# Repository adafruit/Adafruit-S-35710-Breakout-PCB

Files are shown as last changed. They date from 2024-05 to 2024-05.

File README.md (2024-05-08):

## Adafruit S-35710 Low-Power Wake Up Timer Breakout - STEMMA QT / Qwiic PCB

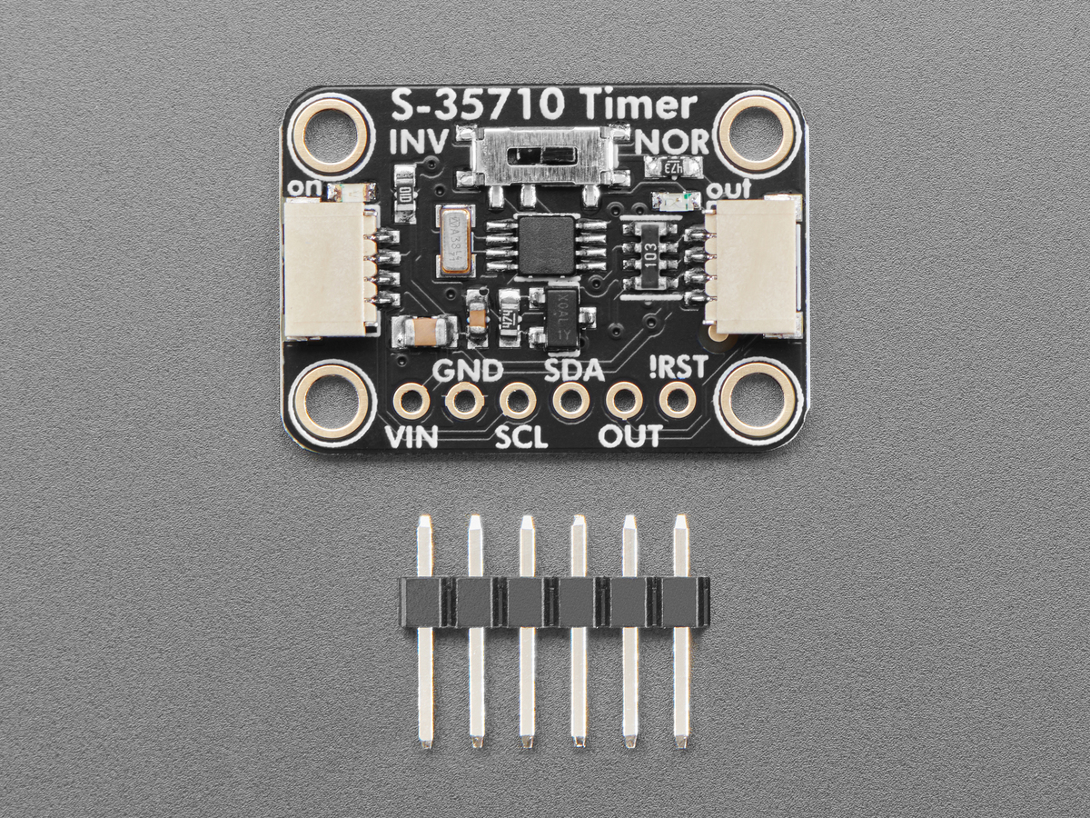
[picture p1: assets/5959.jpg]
<a href="http://www.adafruit.com/products/5959"><br/>
Click here to purchase one from the Adafruit shop</a>

PCB files for the Adafruit S-35710 Low-Power Wake Up Timer Breakout - STEMMA QT / Qwiic. 

Format is EagleCAD schematic and board layout
* https://www.adafruit.com/product/5959

### Description

The Adafruit S-35710 Wake Up Timer is a low power 'watchdog timer' chip that can be programmed to alert with a digitally-configurable alarm from 1 second up to 194 days, thanks to a 24-bit second counter. It's an interesting alternative to a real time clock or internal sleep timer and might be useful for some ultra-low-power projects that want to have a separate (and possibly separately-powered) chip to handle time-keeping and alarms. We covered this component on EYE ON NPI and thought it would make for a nice breakout in the shop.

Usage is pretty simple: on I2C write of the timer register, the chip starts counting from 0 seconds up and the OUT pin goes high. When the count matches the timer register, the OUT pin goes low. Simple, and like we mentioned, it's very low power, drawing only 0.2uA. The output is open-drain, and if you want to have it be inverted, there's a switch that will put the signal through an N-channel FET so the polarity goes the other way.

One thing to note, is that on power-up the OUT line is default low, which means its not good for a low-power sleep manager, only for watch-dog-like timings. That is to say, you cannot connect this to your microcontroller's reset or enable line to self-depower because it will be disabled/reset when powered up. Still, maybe a useful chip for some folks who want to signal after a long delay or have a more complex power management scheme.

To get you going fast, we spun up a custom-made PCB in the STEMMA QT form factor, making it easy to interface with. The STEMMA QT connectors on either side are compatible with the SparkFun Qwiic I2C connectors. This allows you to make solderless connections between your development board and the S-35710 or to chain it with a wide range of other sensors and accessories using a compatible cable.

### License

Adafruit invests time and resources providing this open source design, please support Adafruit and open-source hardware by purchasing products from [Adafruit](https://www.adafruit.com)!

Designed by Limor Fried/Ladyada for Adafruit Industries.

Creative Commons Attribution/Share-Alike, all text above must be included in any redistribution. 
See license.txt for additional details.

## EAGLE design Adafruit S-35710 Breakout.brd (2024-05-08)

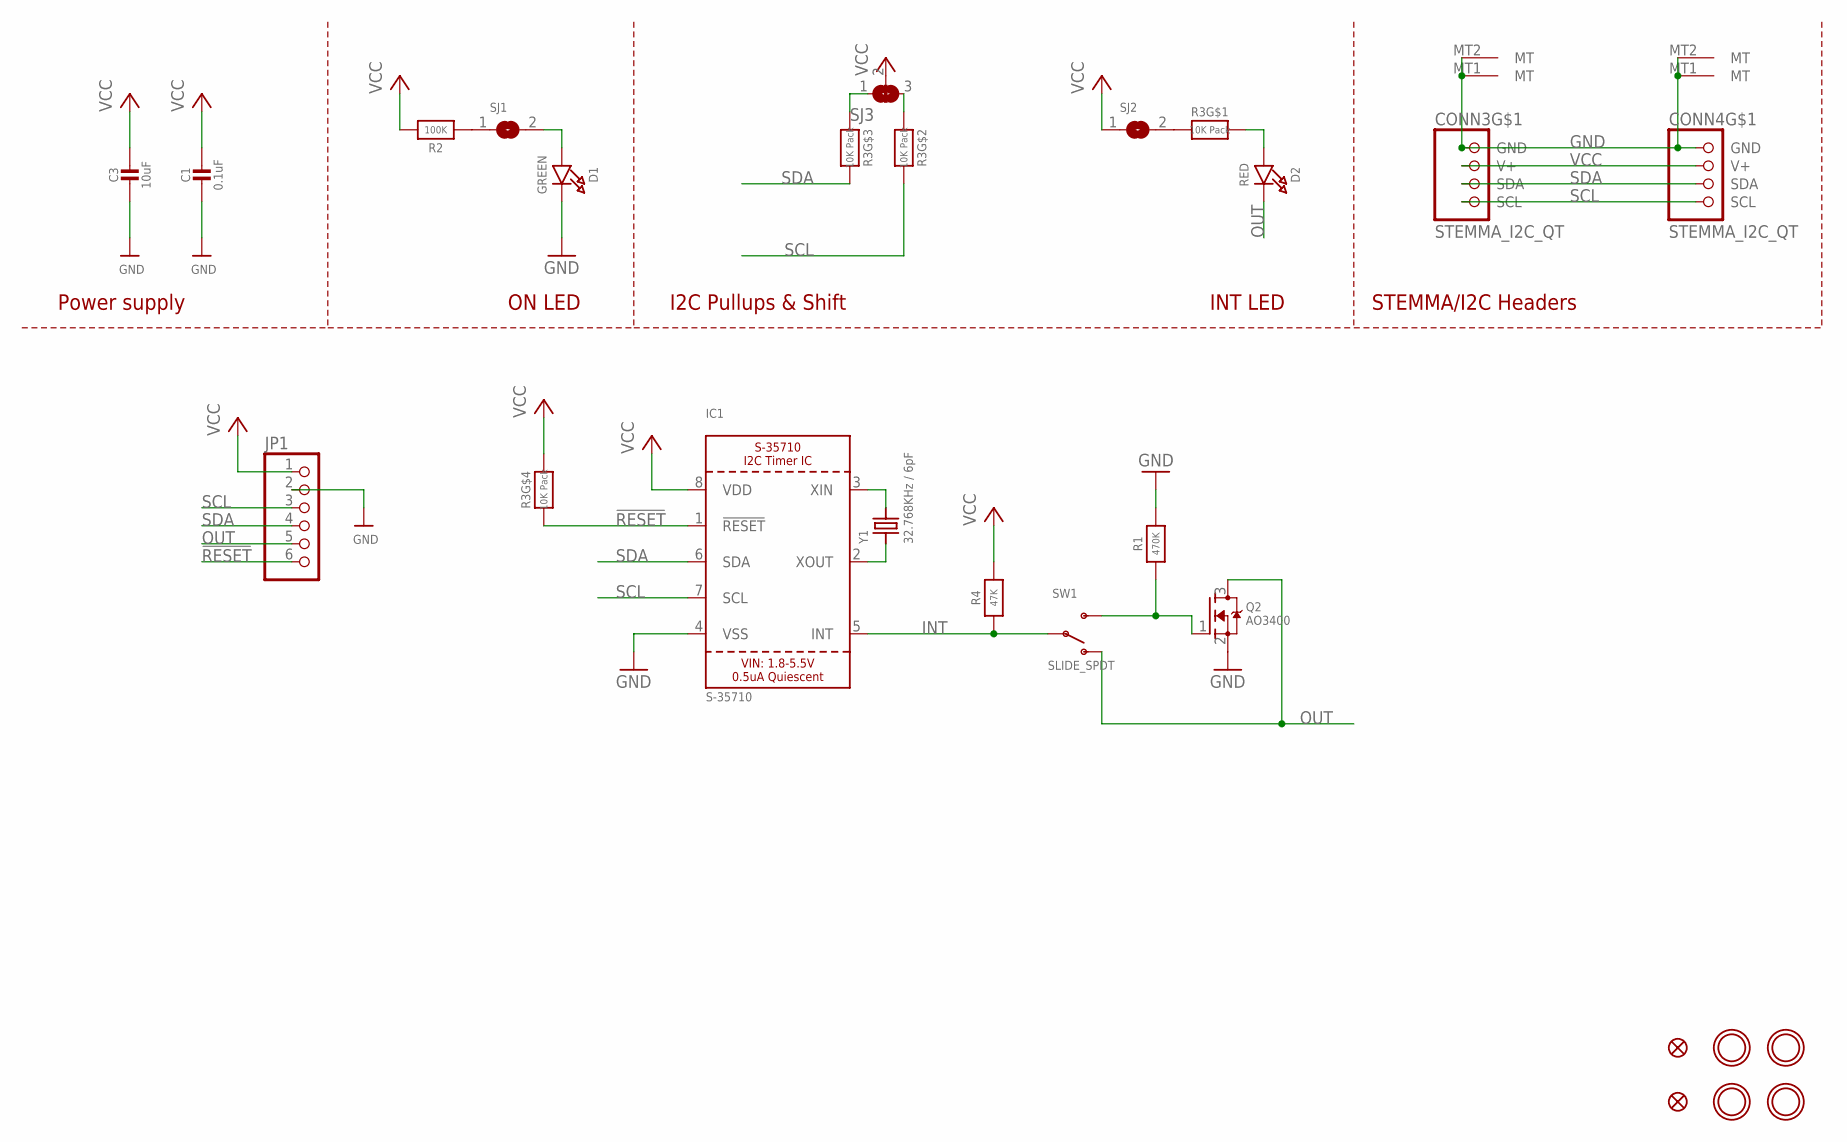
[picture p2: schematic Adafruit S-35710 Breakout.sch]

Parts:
C1: 0.1uF; 0603-NO
C3: 10uF; 0805-NO
CONN3, CONN4: STEMMA_I2C_QT; JST_SH4
D1: GREEN; CHIPLED_0603_NOOUTLINE
D2: RED; CHIPLED_0603_NOOUTLINE
FID3, FID4: FIDUCIAL_1MM
IC1: S-35710; MSOP8_0.65MM
JP1: HEADER-1X670MIL; 1X06_ROUND_70
Q2: AO3400; SOT23-WIDE
R1: 470K; 0603-NO
R2: 100K; 0603-NO
R3: 10K Pack; RESPACK_4X0603
R4: 47K; 0603-NO
SJ1, SJ2: SOLDERJUMPERCLOSED; SOLDERJUMPER_CLOSEDWIRE
SJ3: SOLDERJUMPER_2WAY; SOLDERJUMPER_2WAY_OPEN_NOPASTE
SW1: SLIDE_SPDT; SPDT_SMT_SSSS811101
U$1, U$17, U$19, U$21: MOUNTINGHOLE2.5; MOUNTINGHOLE_2.5_PLATED
Y1: 32.768KHz / 6pF; XTAL3215

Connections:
!RESET: IC1.1 (!RESET), JP1.6, R3.4 (1)
GND: C1.2, C3.2, CONN3.1 (GND), CONN3.MT1 (MT), CONN3.MT2 (MT), CONN4.1 (GND), CONN4.MT1 (MT), CONN4.MT2 (MT), D1.C, IC1.4 (VSS), JP1.2, Q2.2 (S), R1.2
INT: IC1.5 (INT), R4.1, SW1.B
unnamed: D1.A, SJ1.2
unnamed: R3.1, SJ2.2
unnamed: R2.1, SJ1.1
unnamed: D2.A, R3.8 (2)
unnamed: IC1.3 (XIN), Y1.P$2 (2)
unnamed: IC1.2 (XOUT), Y1.P$1 (1)
unnamed: R3.3 (1), SJ3.1
unnamed: Q2.1 (G), R1.1, SW1.C (S)
unnamed: R3.2 (1), SJ3.3
OUT: D2.C, JP1.5, Q2.3 (D), SW1.A (O)
SCL: CONN3.4 (SCL), CONN4.4 (SCL), IC1.7 (SCL), JP1.3, R3.7 (2)
SDA: CONN3.3 (SDA), CONN4.3 (SDA), IC1.6 (SDA), JP1.4, R3.6 (2)
VCC: C1.1, C3.1, CONN3.2 (V+), CONN4.2 (V+), IC1.8 (VDD), JP1.1, R2.2, R3.5 (2), R4.2, SJ2.1, SJ3.2

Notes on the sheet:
I2C Pullups & Shift
STEMMA/I2C Headers
ON LED
Power supply
INT LED

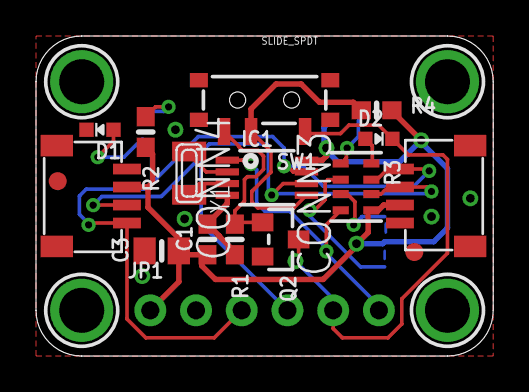
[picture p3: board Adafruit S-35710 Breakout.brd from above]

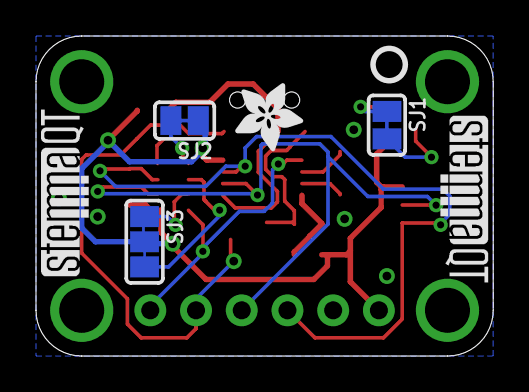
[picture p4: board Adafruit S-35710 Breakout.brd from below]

Board: 2 copper layers, 25.4 x 17.8 mm, 47 parts (15 on the bottom side), 16 nets.

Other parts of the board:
PLABEL0: PLABEL0
PLABEL1: PLABEL1
PLABEL2: PLABEL2
PLABEL3: PLABEL3
PLABEL4: PLABEL4
PLABEL5: PLABEL5
PLABEL6: PLABEL6
PLABEL7: PLABEL7
PLABEL8: PLABEL8
PLABEL9: PLABEL9
PLABEL10: PLABEL10
PLABEL11: PLABEL11
PLABEL13: PLABEL13
PLABEL14: PLABEL14
PLABEL15: PLABEL15
PLABEL16: PLABEL16
PLABEL17: PLABEL17
PLABEL18: PLABEL18
PLABEL19: PLABEL19
U$22: ADAFRUIT_3.5MM
U$25: PCBFEAT-REV-040
U$30, U$31: STEMMAQT

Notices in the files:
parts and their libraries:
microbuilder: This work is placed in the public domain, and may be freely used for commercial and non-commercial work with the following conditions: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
